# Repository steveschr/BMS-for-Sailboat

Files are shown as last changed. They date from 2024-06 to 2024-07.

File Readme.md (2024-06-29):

# Fully configurable BMS and charge controller with balance for 4S LiFePO4 battery bank on a cruising sailboat.  

# Description & Purpose

* Prevents load dump by controlling charge sources.
* Measures and monitors pack and cell voltage as well as current load/charge of battery.  
* Starts and stops charge sources at user defined limits.  The charge sources are then programmed as desired.
* All settings as well as errors saved to EEPROM.  
* Single knob control with 4 line LCD display.  
* Configurable alarm thresholds.
* External alarm ready 
* Pack disconnect function ready as suggested by ABYC.  
* Can easily be modified for seperate charge & load busses.
* Charge lockout below freezing.

# Genesis

I wanted to install LiFePO4 batteries on my cruising sailboat and didn't like the feature set of the available BMS and control system options.  I didn't like the idea of a drop in battery that might decide to disconnect or do a load dump when it wanted to.  (On a boat that means the worst possible moment)  I didn't want to add a start battery and the associated inefficiencies and complexity.  When I started this project there wasn't much hardware available.  That's changed some but I still like this better.
For example I may want to keep the batteries at a specific SOC instead of charging to full all the time.  There's no way the alternator regulator or solar controller can know state of charge except by voltage.  I wanted control by SOC and voltage as well as full BMS protection.
Determinining lithium battery state of charge (SOC) by cell voltage alone is too imprecise and it's impossible to determine health of pack by pack voltage.
  
After trying a few other methods I ended up using a simple resistor voltage divider circuit for the front end.  Yeah I guess I feel a little embarassed I didn't do something more sophisticated but since there's only 4 cells in series it works well, the biggest trouble is error trapping for an open cell connection.

I've been using this system successfully for several years.   

# Credits
Stuart Pittaway - Lot's of inspiration here.  Robert Kirberich (solder-stencil.me), Majenko Technologies (MCP3208 library), lots of snips from around the net I can't recall to credit, MCUDude for Mightycore

# Operation 
Cell voltage is determined by resistor voltage dividers and MCP3208 analog to digital converter.  
Accuracy better than +-5 mV.  Can be tuned for variations in resistor values.  Current is read by a 200A 50mV shunt output amplified by INA213 and read by MCP3204.  
27mA current draw, 68mA when LCD lit.  The drain caused by the resistor dividers is .25mA or less per cell.

# Construction
Main board, Balance board, temperature sensor boards and current shunt board.  A combination of surface mount and through hole components.  I assembled these with the printed stencil and a hot plate for the surface mount.
EasyEDA format schematic & board as well as gerbers for all.  STL files for 3d printing of required cases and mounting bases.
3D print using PetG or similar.  PLA is too brittle.  Boards & LCD fit on printed pins, flatten pins with a soldering iron.  No screws needed.
3D printed stencil for main board (Thank you to https://solder-stencil.me/ )
Compiled on Arduino IDE with MCUdude's excellent MightyCore (Atmega644/BOD 4.3/No Bootloader/External 16MHz/LTO Enabled/Bobuino/644-644A  Required LCD & MCP3208 libraries included.  Any compatible programmer should work, I use STK500, Atmel ICE, Tiny USB.

Main board

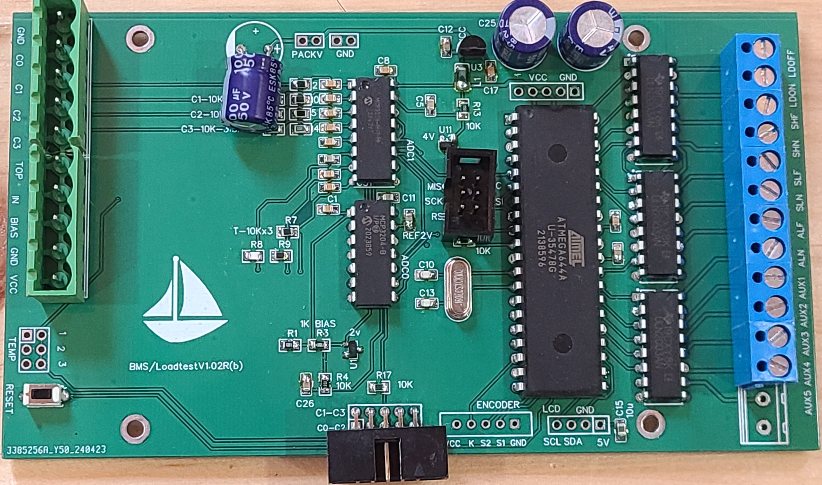
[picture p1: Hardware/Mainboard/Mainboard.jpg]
main board


Shunt board

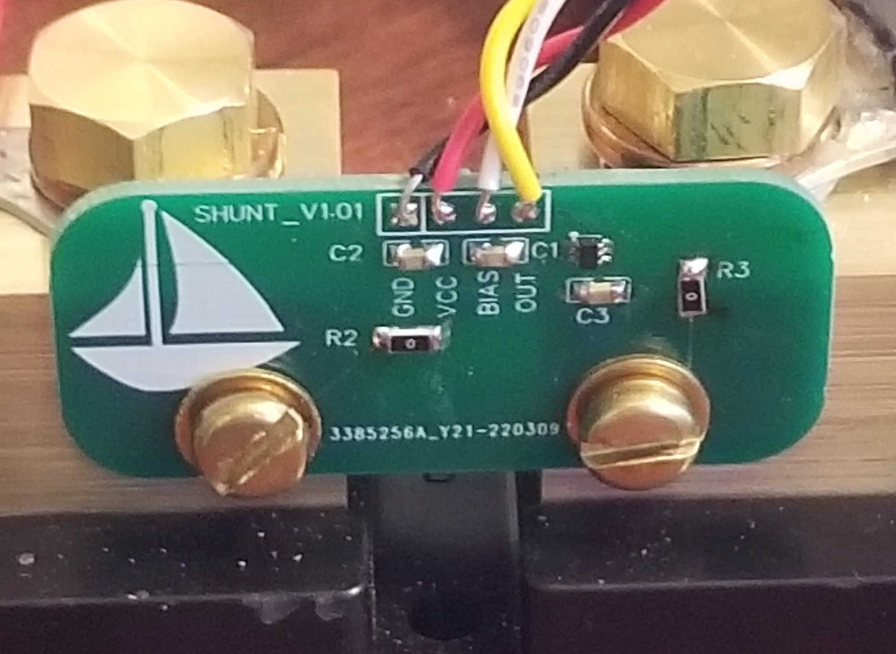
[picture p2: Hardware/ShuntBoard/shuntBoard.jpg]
shunt board


Balance board

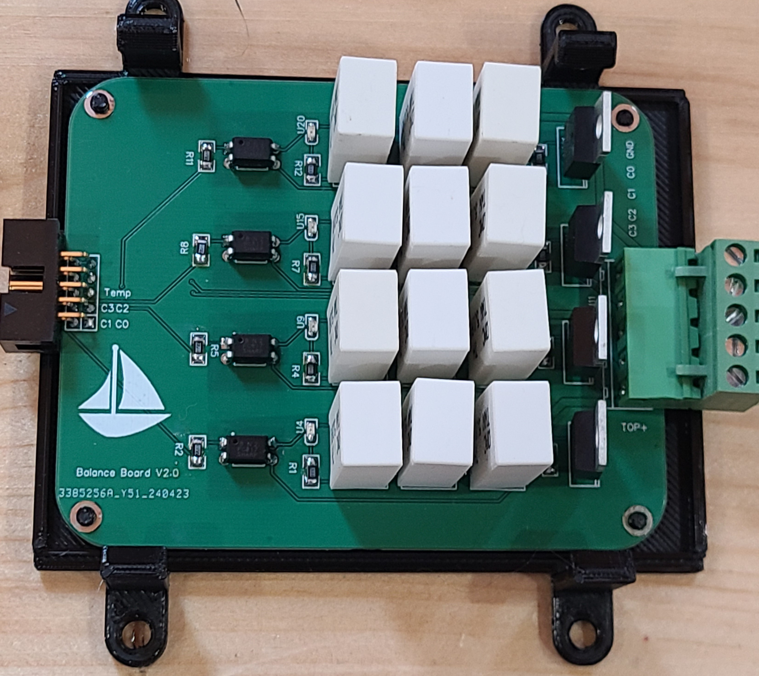
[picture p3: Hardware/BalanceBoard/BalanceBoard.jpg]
balance board


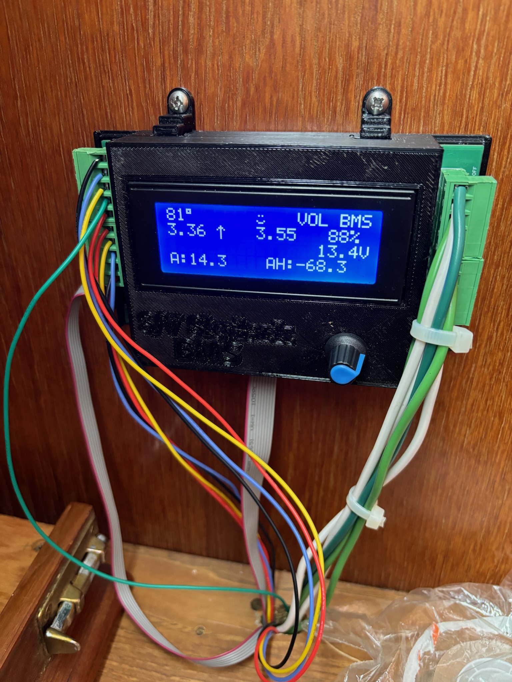
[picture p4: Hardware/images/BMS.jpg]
  

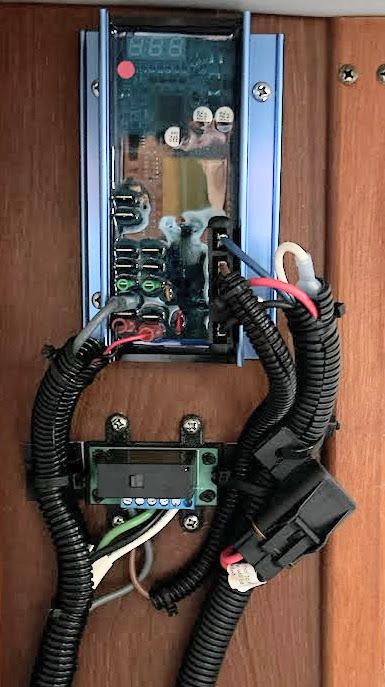
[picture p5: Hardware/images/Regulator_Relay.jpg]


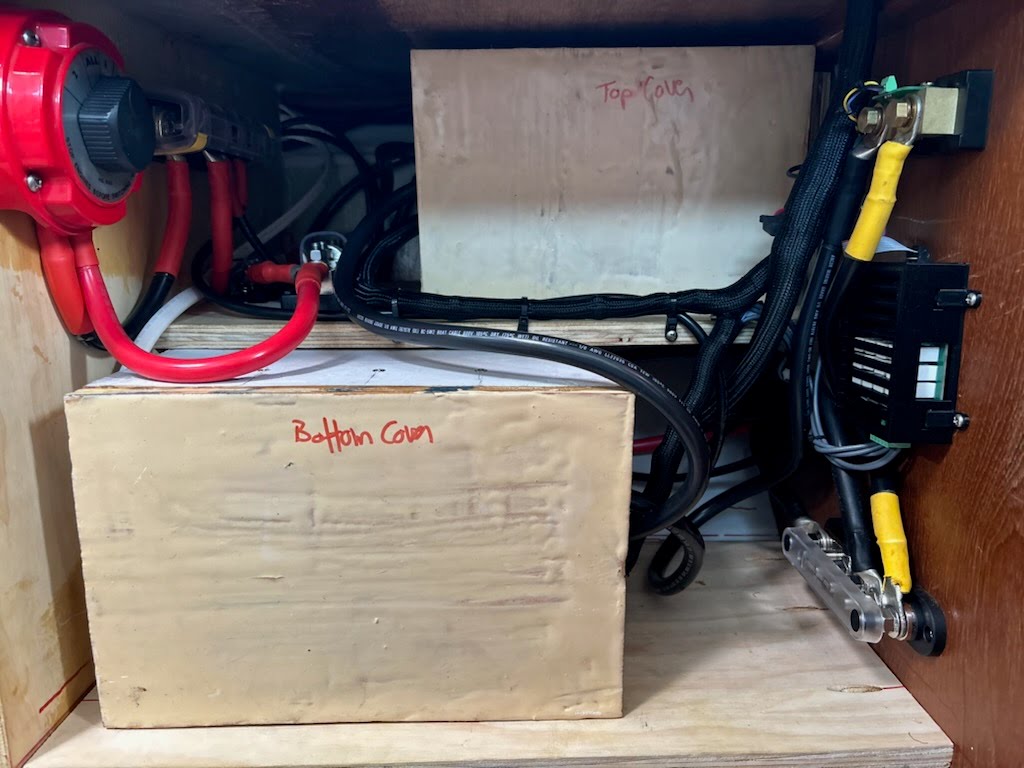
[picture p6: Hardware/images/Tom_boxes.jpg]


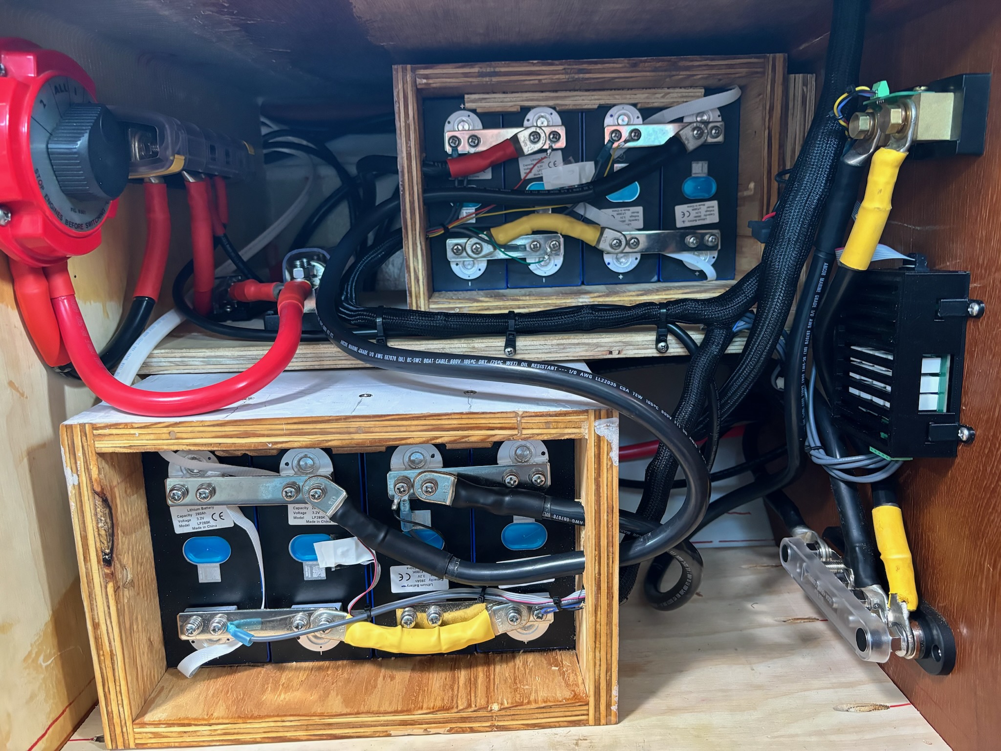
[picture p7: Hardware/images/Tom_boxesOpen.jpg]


# hardware
Atmega 644 based.  

# Software
Compiled on Arduino IDE with MCUdude's excellent MightyCore

# BOM

There's a set of BOMs in the hardware folder, 1 for each board.  Wiring and terminal blocks are in the [Extras BOM](Hardware/extrasbom.md)

# Installation
## Modifications to boat
Install latching relays to control AC input to shore charger, solar panel input to solar charger, ign signal to alternator relay.  Provision for latching relay to protect bank; I have a friend that uses this to shut off the fridge when the dock power goes out for long enough to drain the battery.  See [the overview](./Schematic_Typical-Layouts.pdf) and an [as built](./LittleWillieAsBuilt.pdf)
My boat is out of the water in the summer, I disconnect the BMS from the battery and the battery from the boat for storage.

# Warning
Lithium batteries can be dangerous.  If you build and or use this device it's at your own risk.

# Details
See individual hardware folders.

# Future Plans
Maybe add Bluetooth.  Add terminal connectors for the battery temp sensors.

## Parameter Menu Settings

Bank Capacity 
Total bank capacity in AmpHours.

Start Charge
When in Volt charge mode triggers start charge.  Constrained to a minimum of 60mV below StopCharge Voltage

Stop Charge
In either Volt or SOC charge mode triggers stop charge.  Constrained to a minimum of 50mV above StartCharge Voltage

SOC Start  
% charge to start charging when in SOC mode.

SOC Stop 
% charge to stop charging when in SOC mode.  Voltage also affects charge stop in SOC mode.

Charge Mode 
SOC or Voltage. In SOC mode, Charge will start if measured SOC falls below SOCstart parameter (Ignores Start Charge V )  and will stop when either SOC Stop or Stop Charge V is reached.  If Stop Charge V is set relatively low, charge will start again as voltage falls below the stop threshold and continue cycling until calculated SOC reaches a level above SOC Start.   SOC will NOT reach SOC stop in this scenario.

Charging starts when, depending on mode either SOC or voltage falls below start threshold.
Charging stops when depending on mode either voltage or SOC target is met or either temperature hi or low or voltage high (this is redundant) alarm is set.

When in VOL mode the 2nd row of the display shows current cell voltage on left and target voltage on right.  Up arrow for charging or ready charge and down arrow for not charging.  Target voltage is either start or stop voltage depending on whether charging or discharging.

When in SOC mode target SOC is on the left, current SOC on right.  Arrow indicates charge or discharge.  In both modes the up arrow indicates charge or charge ready and is not an indicator of actual charging status which is visible in the bottom left of the display.   

Chg To Full Now 
Starts charging as if the start parameter had been reached.  Charge continues until the stop parameter in current chargeMode is reached.

Efficiency 
% efficiency of charge.  No Peukert’s calculation as it’s assumed to be about 1 for LiFePo4.

HV Alarm
High Voltage Alarm. Sets alarm & stops charge.  Clears at -5mV.

LV Alarm 
Low Voltage Alarm. Sets alarm & allows charge.  Clears at +5mV

HV Disconnect
Assuming a bank protection relay boat & charging shut off until voltage falls below HVAlarm.  Will not stop the boat if PackVoltage < 15.6v.

LV Disconnect
Assuming a bank protection relay; boat & charging shut off until voltage rises above LVAlarm. 
Will not stop the boat if PackVoltage > 10.0v.

maxDrift
In millivolts.  If setting is reached an alarm will set but charging will continue.

C0Trim  C1Trim  C2Trim  C3Trim 
Enter in mV any offset required so the display matches actual cell voltages.  

Balance Allow V 
Voltage to start balance.  Highest cell is used.  Needs the balance board connected.  

Show Cells 
1st screen shows voltage of all cells, # of charge cycles since startup, cell drift in mV and # of times each cell has been balanced.  2nd screen shows system voltages, 3rd screen shows hi & lo cell, amperage, drift, pack & total voltage at end of last charge cycle.

Show Temps
Shows temp sensor readings battery & balance board

Show Alarms
Shows all saved previous alarms, key sensor readings at last alarm and alarm flags that were set at the time of last alarm.

Clear Alarm
Clears all active & inactive alarms.

Mode 
Choose BMS, OFF or DUM.  DUM turns on the boat and allows charging with no protection.  DUM mode display shows highest cell voltage and SOC.   Switching back to BMS restores full management.  OFF mode prevents charging. 

Encoder Direction
Changes direction of the encoder knob.  Used only for initial setup if required.  The change is immediate so twisting the knob in one direction changes the value 1-0-1-0-1-0 etc.

SOC
Set current SOC   This may be useful for initial install or testing.

Shunt Polarity 
Allows connecting shunt in either direction.  Use if Amps display reversed.

Number of Temp Sense
Choose correct # of battery temp sensors used

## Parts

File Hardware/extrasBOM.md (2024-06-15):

# Additional parts

* You'll need some of this stuff too.

[Relay ADJH24112 - for control of charge sources](https://www.digikey.com/en/products/detail/panasonic-electric-works/ADJH24112/7537062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)

[Relay G9TB-K1ATH-E DC12  - 120A for load or charge bus](https://www.digikey.com/en/products/detail/omron-electronics-inc-emc-div/G9TB-K1ATH-E-DC12/8593134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)

[24ga silicone wire](https://www.aliexpress.us/item/3256806064207395.html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) 

[Quick disconnects for wire to board](https://www.aliexpress.us/item/2251832631116552.html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) But the pins are oversize and must be trimmed.

[Or terminal blocks ED120/5DS](https://www.digikey.com/en/products/detail/on-shore-technology-inc/ED120-5DS/265403)

[Terminal block for shunt board OSTVN04A150](https://www.digikey.com/en/products/detail/on-shore-technology-inc/OSTVN04A150/1588864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)

[Rotary encoder](https://www.aliexpress.us/item/3256802224106936.html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)

[STK 500 programmer](https://www.aliexpress.us/item/3256806049996635.html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)

[I2c 20x4 LCD](https://www.aliexpress.us/item/3256801435340143.html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)

[Balance interface cable 1.27 pitch 10 conductor](https://www.aliexpress.us/item/2251832811689611.html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)

[Cable ends 2x5](https://www.aliexpress.us/item/3256802188284715.html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)

[Header connector wire to board 2.54 2x5](https://www.aliexpress.us/item/3256805956473629.html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)

[Murata 3020-01101-0 shunt or similar](https://www.mouser.com/ProductDetail/Murata-Power-Solutions/3020-01101-0?qs=35WhQNrE6p34sz4RDoVvJQ%3D%3D)

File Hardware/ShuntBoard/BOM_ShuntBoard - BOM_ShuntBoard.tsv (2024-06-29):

Name | Designator | Footprint | Quantity | Manufacturer Part | Manufacturer
0R | R2,R3 | 1206 | 2
.1uF | C2,C3 | C0805 | 2 | KGM21NR71E104KT | DELETE C1
INA214AIDCKR | U1 | SC-70-6_L2.2-W1.3-P0.65-LS2.2-BR | 1 | INA214AIDCKR | TI

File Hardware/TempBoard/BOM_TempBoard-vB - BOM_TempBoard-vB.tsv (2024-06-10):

Name | Designator | Footprint | Quantity | Manufacturer Part | Manufacturer
NTCS0805E3103FLT | R2 | R0805 | 1 | NTCS0805E3103FLT

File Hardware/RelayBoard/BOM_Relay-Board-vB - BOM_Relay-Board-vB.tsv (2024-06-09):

Name | Designator | Footprint | Quantity | Manufacturer Part | Manufacturer
ADJH23012 | U1 | RELAY-TH_PANASONIC_ADJH241XX | 1 | ADJH24112 | PANASONIC

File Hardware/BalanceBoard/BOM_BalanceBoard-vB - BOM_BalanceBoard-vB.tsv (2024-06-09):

Name | Designator | Footprint | Quantity | Manufacturer Part | Manufacturer
IRLB8743PBF | Q1,Q2,Q3,Q4 | TO-220(TO-220-3) | 4 | IRLB8743PBF | IR
100 | R1,R4,R7,R12 | R1206_1 | 4 | RT1206FRE07100RL
220 | R2,R5,R8,R11 | R1206_1 | 4 | RT1206FRE07220RL
100K | R3,R6,R10,R13 | R1206_1 | 4 | RT1206FRE07100KL
NTCS0805E3103JHT | R9 | R0805 | 1 | NTCS0805E3103JHT | Vishay Intertech
TWW5J1R0E | U1,U2,U3,U6,U7,U8,U12,U13,U14,U17,U18,U19 | RES-TH_L12.5-W9.0-P5.00-D1.2 | 12 | TWW5J1R0E | Ohmite
SM0805YCL | U4,U9,U15,U20 | LED0805-RD | 4 | SM0805YCL
FOD817A300 | U5,U10,U16,U21 | DIP-4 | 4 | FOD817A300

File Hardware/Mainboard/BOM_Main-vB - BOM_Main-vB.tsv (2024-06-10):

Name | Designator | Footprint | Quantity | Manufacturer Part | Manufacturer
MCP3204-CIP | ADC0 | DIP14 | 1 | MCP3204-BI/P | Microchip Tech
MCP3208-CI_P | ADC1 | DIP16 | 1 | MCP3208-BI/P | Microchip Tech
ATMEGA644A-PU | AT1 | PDIP-40 | 1 | ATMEGA644A-PU | Microchip Tech
.1u | C1,C4,C5,C6,C7,C8,C9,C11,C12,C17,C18,C31,C15,C22 | C0805 | 14 | KGM21NR71E104KT
100uF | C2,C3,C25 | CAP-TH_BD10.0-P5.00-D1.0-FD | 3 | ESK107M050AH1AA
22pF | C10,C13 | C0805 | 2 | C0805C220K3GAC7800
10u | C26 | C0805 | 1 | C0805C106K3PAC7800
1-87215-2 | ICSP | HDR-TH_6P-P2.54-V-M-R2-C3-S2.54-1 | 1 | 1-87215-2 | TE Connectivity
1uH | L1 | L1206 | 1 | ILSB1206ER1R0K
1K | R1,R3,R11, R13, R4 | 805 | 5 | RT0805BRD071KL
10K | R2,R6,R7,R8,R9,R10,R12,R15,R17 | 805 | 9 | RT0805BRD0710KL
5K | R5 | 805 | 1 | RT0805BRD075K1L
3.33K | R14 | 805 | 1 | RT0805BRD073K3L
EVQ-PE505K | RESET | EVQPE505K | 1 | EVQPE505K
LM4040DELT-2.0 | U1 | SOT-23-3_L2.9-W1.3-P1.90-LS2.4-BR | 1 | LM4040CELT-2.0
ULN2003AN | U2,U4,U5 | DIP-16_16P-L20.2-W6.6-P2.54-LS7.6-BL | 3 | ULN2003AN | TI
LP2950ACZ-5.0G | U3 | TO-92-3_L4.9-W3.7-P1.27-L | 1 | LP2950ACZ-5.0/NOPB | ON
LM4040DELT-4.096 | U11 | SOT-23-3_L2.9-W1.3-P1.90-LS2.4-BR | 1 | LM4040CELT-4.1
16Mhz | Y1 | HC49US | 1 | ECS-160-18-4X-CKM

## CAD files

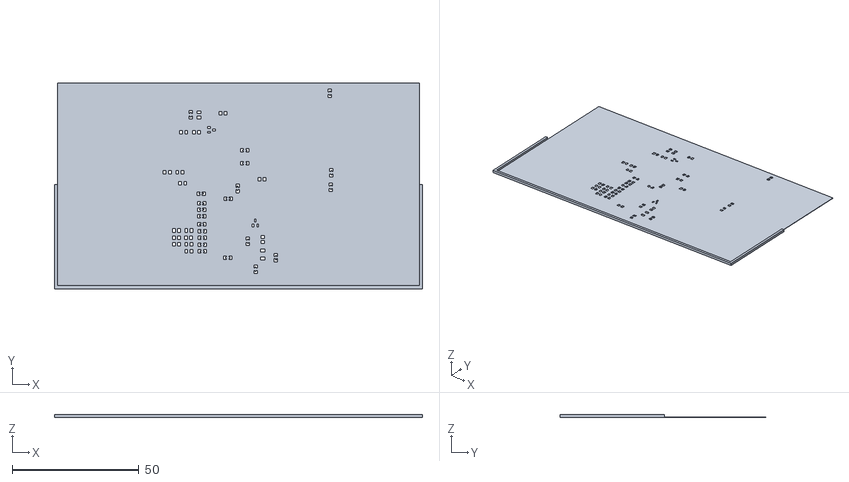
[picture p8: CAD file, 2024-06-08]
Hardware/Mainboard/BMS_Main_Stencil.stl
145.4 x 81.2 x 1.20

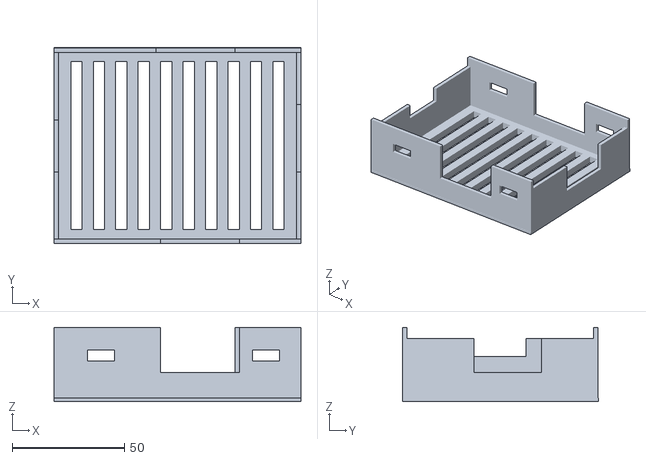
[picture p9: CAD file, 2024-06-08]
Hardware/BalanceBoard/BalanceBoardLid.stl
110.0 x 87.5 x 33.0

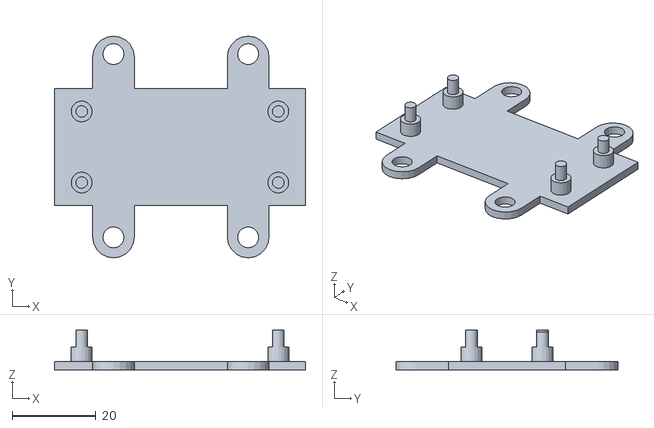
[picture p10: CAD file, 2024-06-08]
Hardware/RelayBoard/RelayBase.stl
60.0 x 53.0 x 9.50

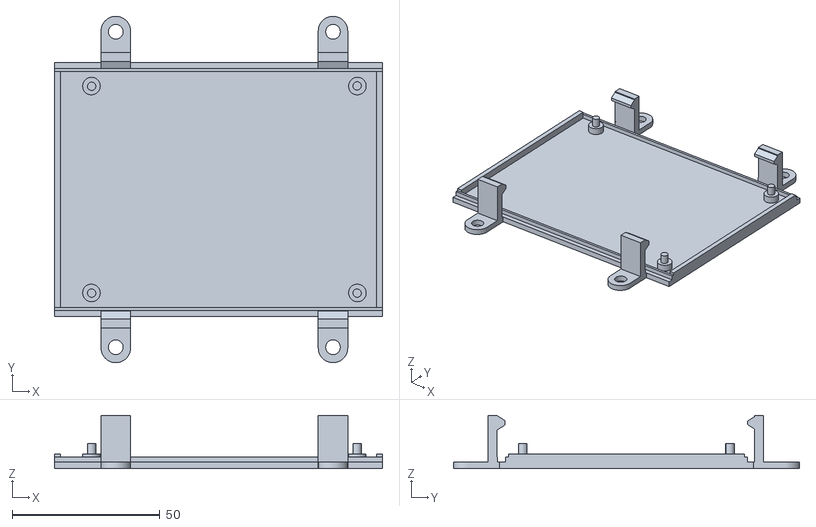
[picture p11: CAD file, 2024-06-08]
Hardware/BalanceBoard/BalanceBoardBase.stl
111.0 x 117.2 x 18.0

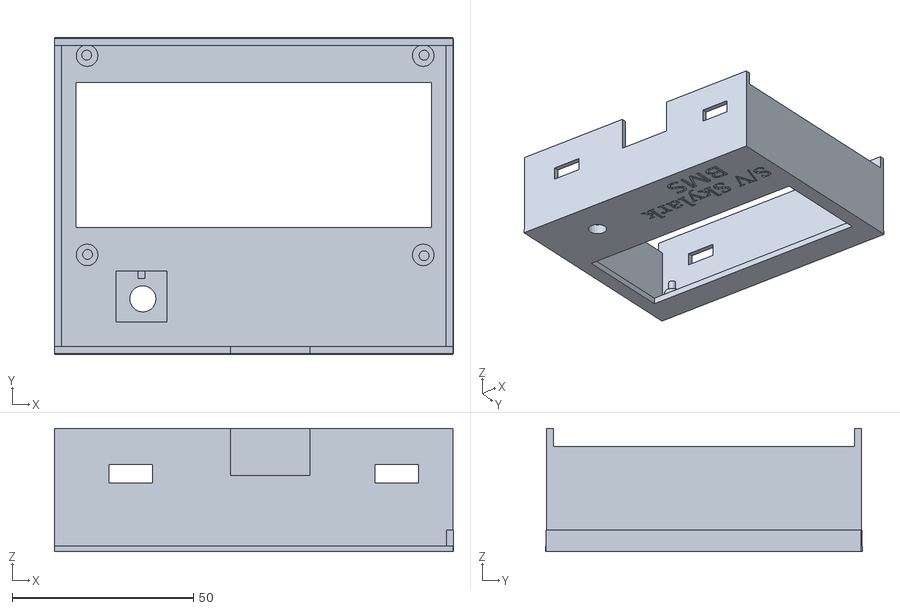
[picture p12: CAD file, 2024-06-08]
Hardware/Mainboard/BMS644Lid-w-pins.stl
110.1 x 87.5 x 34.0

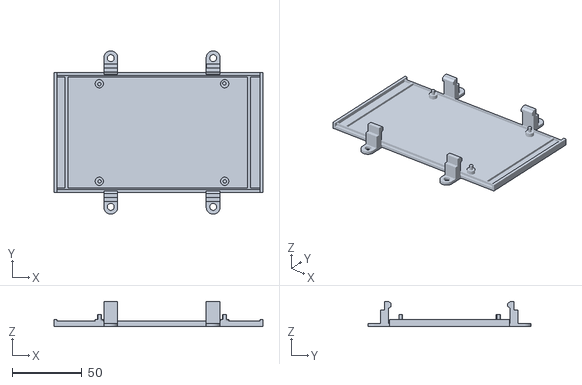
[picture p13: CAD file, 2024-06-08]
Hardware/Mainboard/BMS644Base.stl
150.0 x 117.2 x 18.0

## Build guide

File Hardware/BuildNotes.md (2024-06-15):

* Schematics & boards are in EasyEDA format, gerbers are also in the folders
* There are some errors in the part #s on the schematics but the BOMs are correct.

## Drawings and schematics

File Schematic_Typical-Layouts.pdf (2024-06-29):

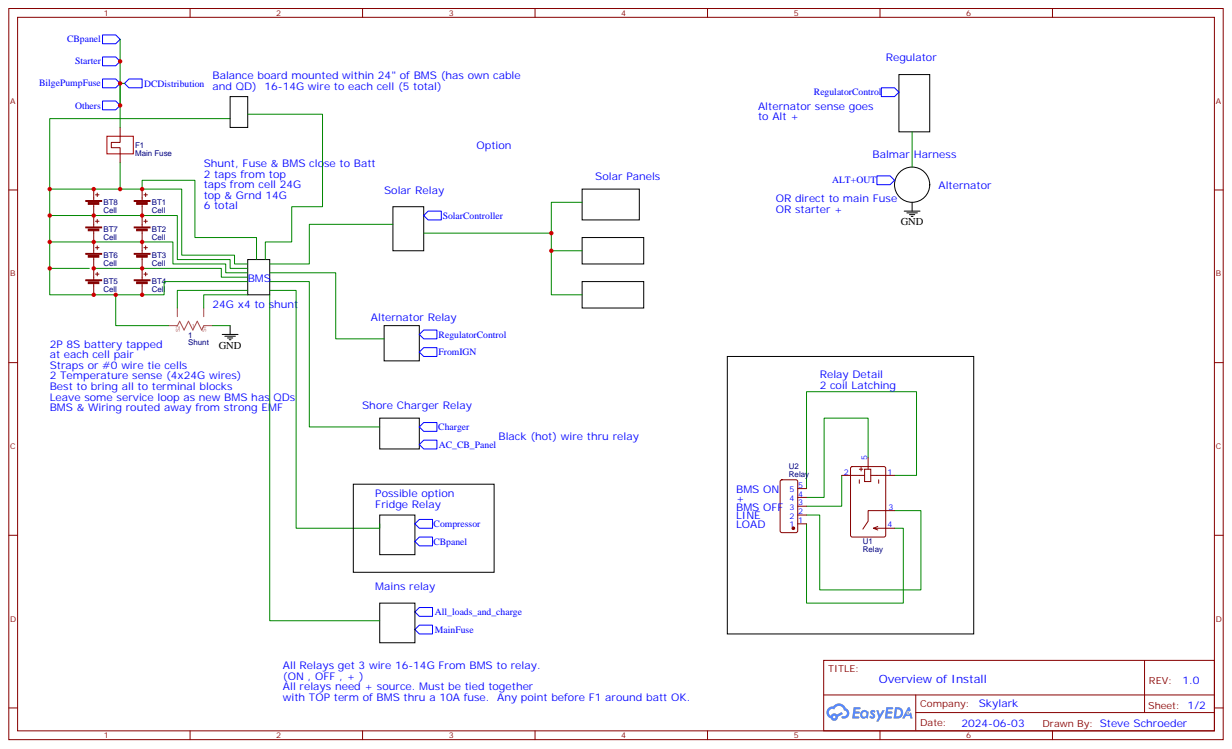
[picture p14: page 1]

Balance board mounted within 24" of BMS (has own cable
and QD) 16-14G wire to each cell (5 total)

Shunt, Fuse & BMS close to Batt
2 taps from top
taps from cell 24G
top & Grnd 14G
6 total

OR direct to main Fuse
OR starter +

2P 8S battery tapped
at each cell pair
Straps or #0 wire tie cells
2 Temperature sense (4x24G wires)
Best to bring all to terminal blocks
Leave some service loop as new BMS has QDs
BMS & Wiring routed away from strong EMF

Black (hot) wire thru relay

All Relays get 3 wire 16-14G From BMS to relay.
(ON , OFF , + )
All relays need + source. Must be tied together
with TOP term of BMS thru a 10A fuse. Any point before F1 around batt OK.

Drawn By: Steve Schroeder

OR

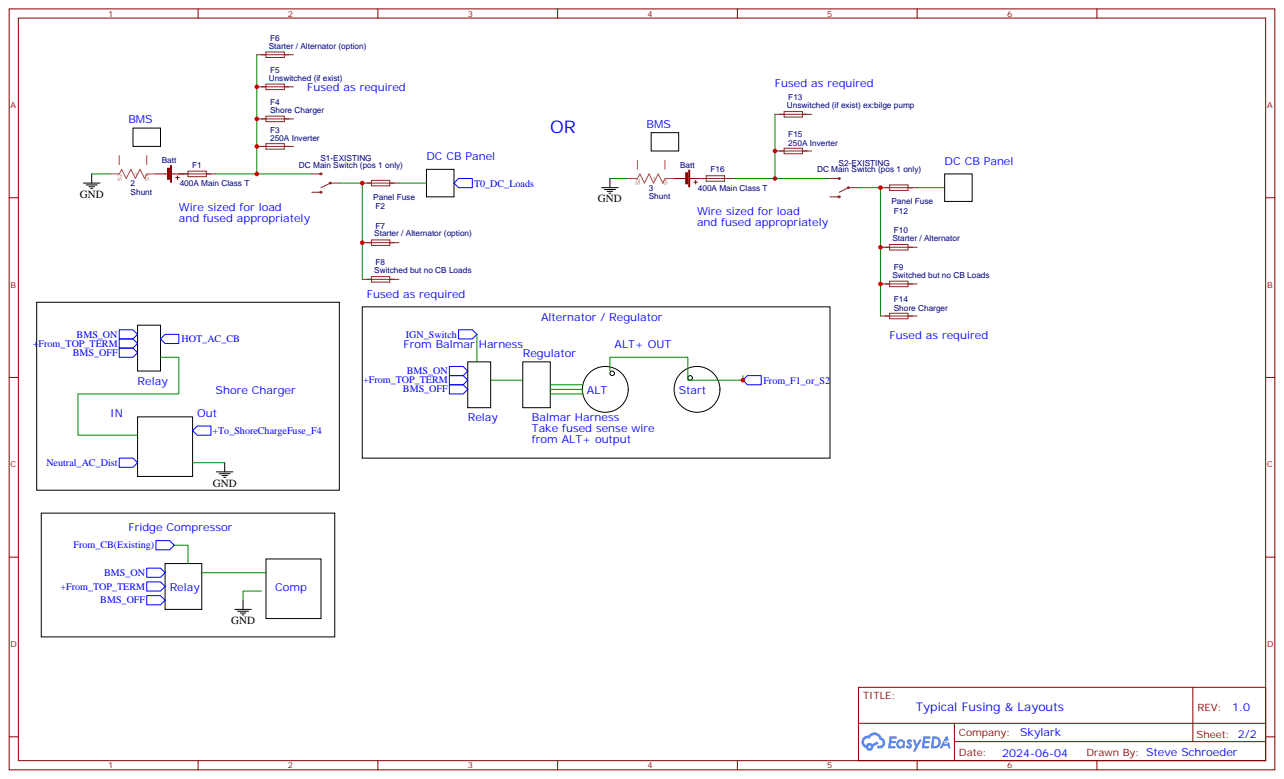
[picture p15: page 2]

Fused as required
Unswitched (if exist) ex:bilge pump

S1-EXISTING
DC Main Switch (pos 1 only)

Batt
400A Main Class T
Wire sized for load
and fused appropriately

S2-EXISTING

Switched but no CB Loads

Balmar Harness
Take fused sense wire
from ALT+ output

Drawn By: Steve Schroeder

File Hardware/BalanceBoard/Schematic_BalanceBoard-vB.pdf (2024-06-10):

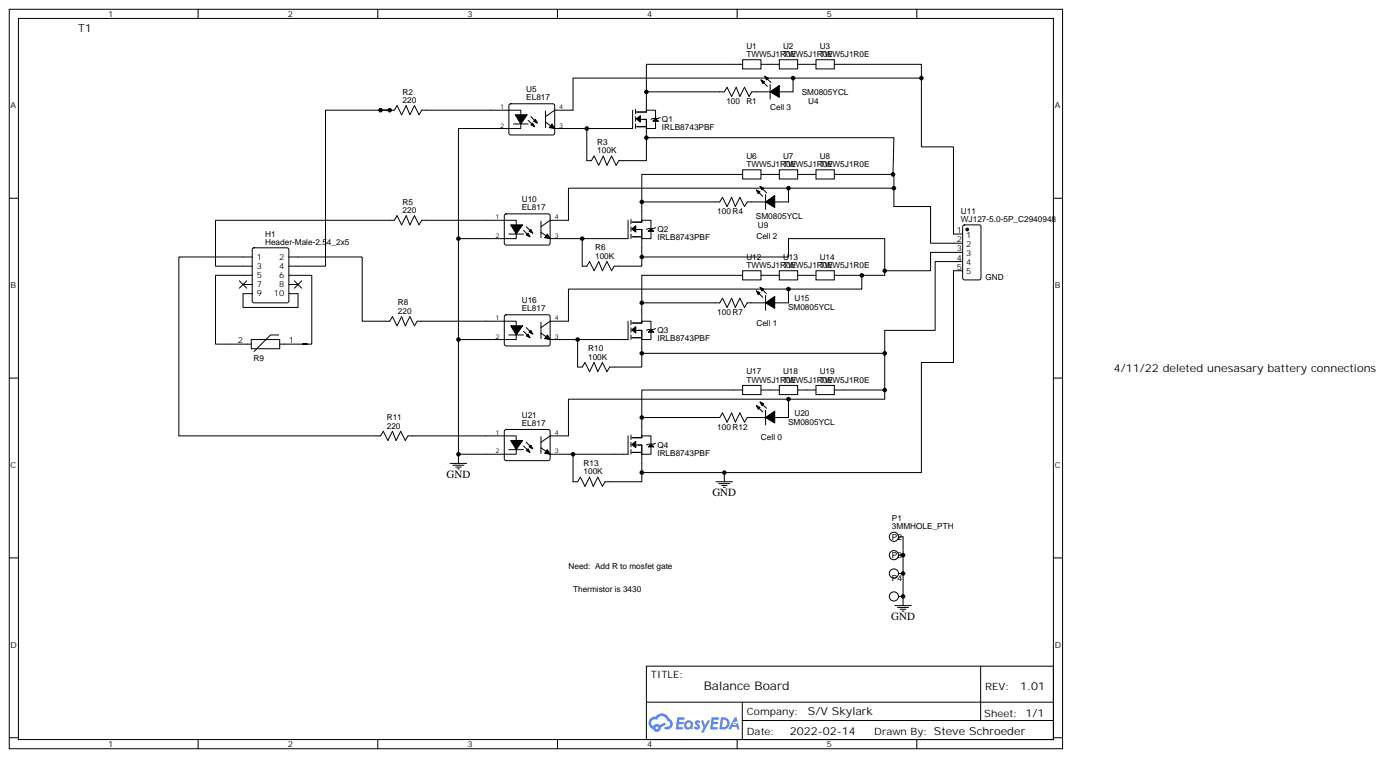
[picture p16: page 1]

4/11/22 deleted unesasary battery connections

Need: Add R to mosfet gate

Drawn By: Steve Schroeder

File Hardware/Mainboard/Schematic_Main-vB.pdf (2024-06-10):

## Ordered boards 4/22/24 BMS/LoadtestV1.02R(b)

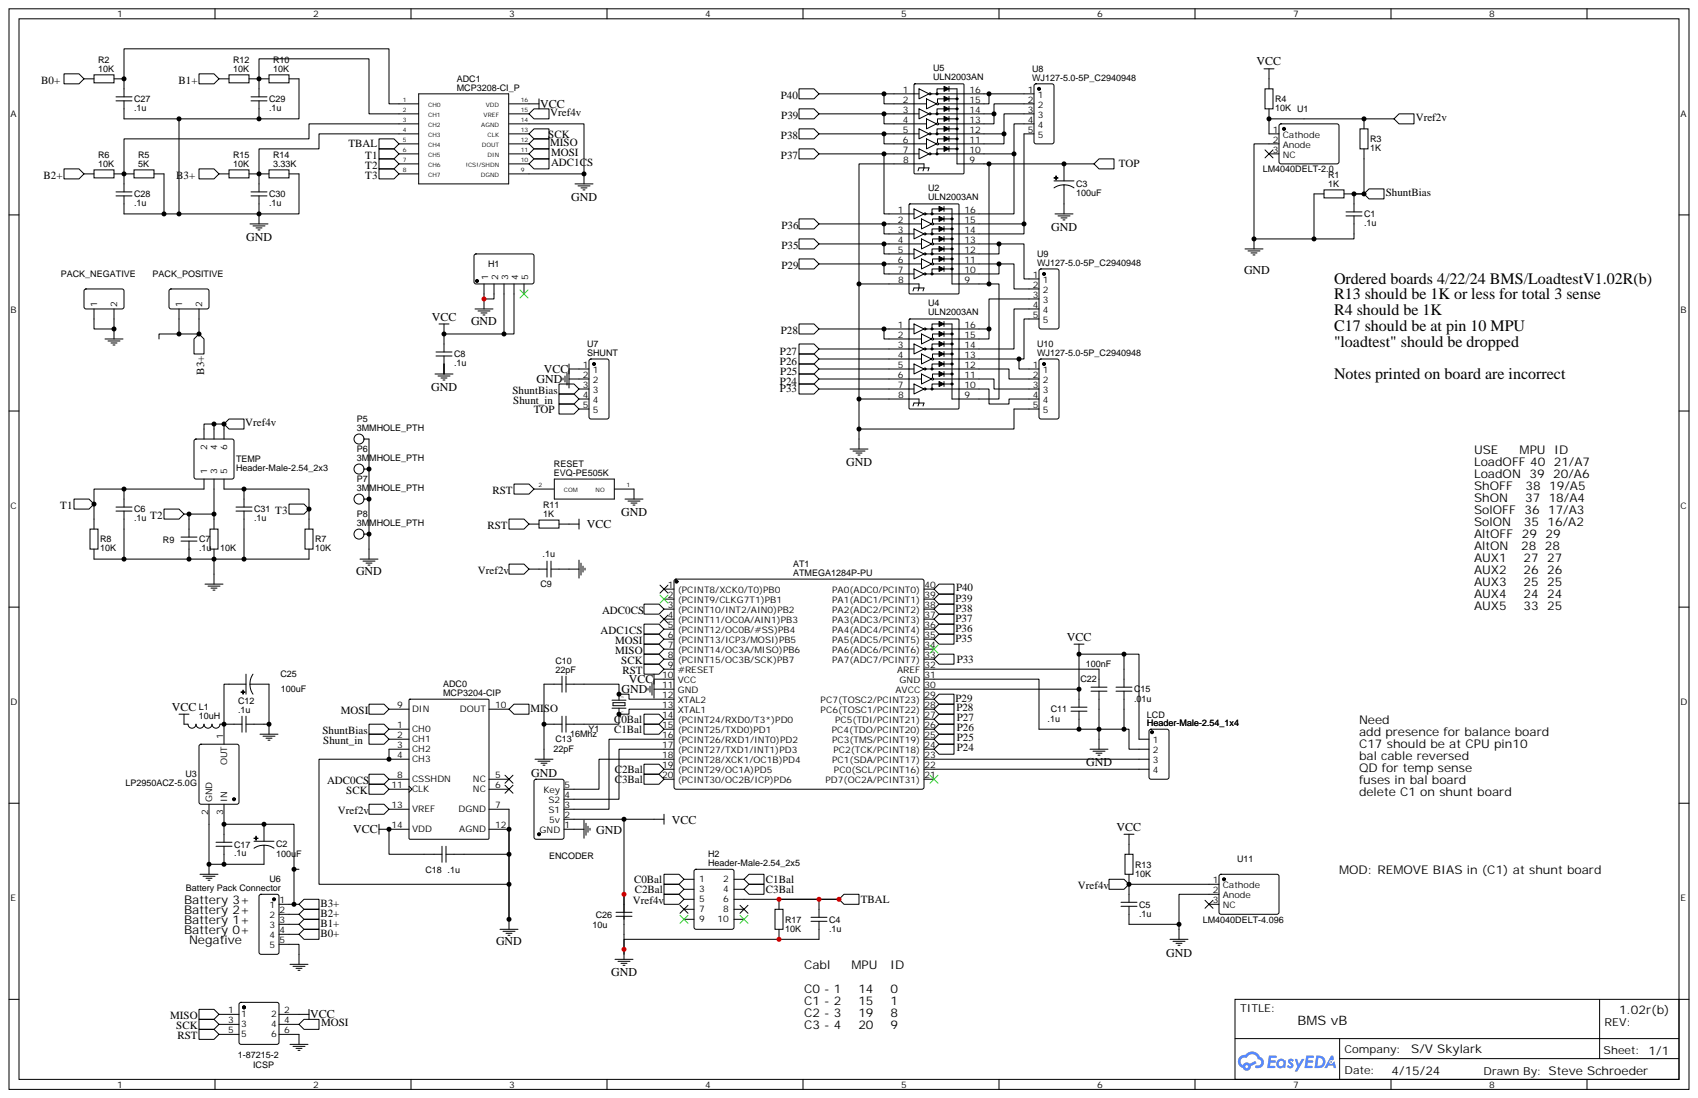
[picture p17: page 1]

R13 should be 1K or less for total 3 sense
R4 should be 1K
C17 should be at pin 10 MPU
"loadtest" should be dropped
Notes printed on board are incorrect

Need
add presence for balance board
C17 should be at CPU pin10
bal cable reversed
QD for temp sense
fuses in bal board
delete C1 on shunt board

MOD: REMOVE BIAS in (C1) at shunt board

Drawn By: Steve Schroeder

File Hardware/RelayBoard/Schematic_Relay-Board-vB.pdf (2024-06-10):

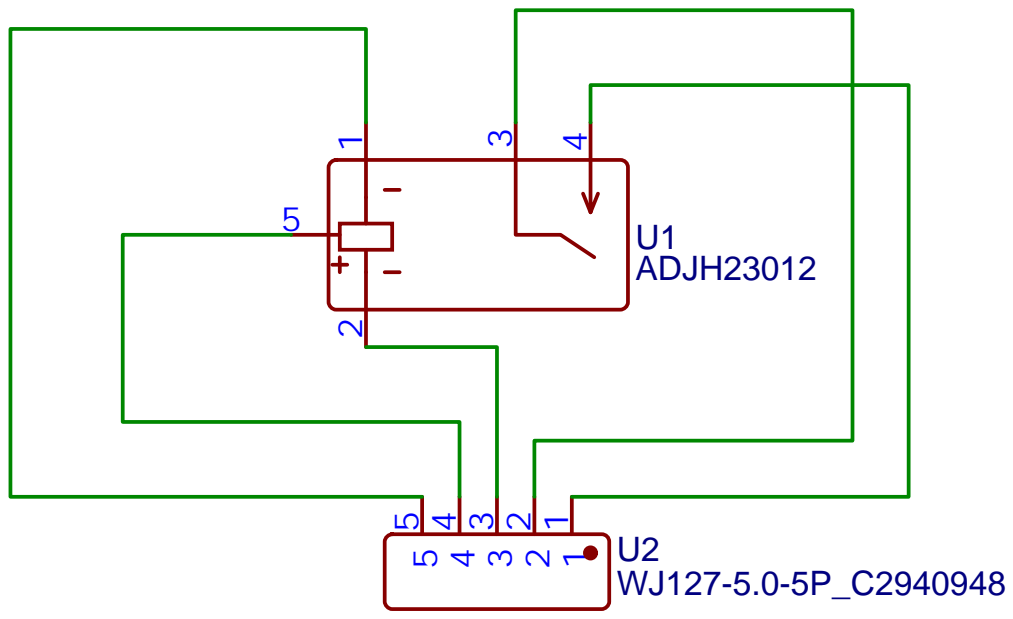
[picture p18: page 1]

Drawn By: Steve Schroeder

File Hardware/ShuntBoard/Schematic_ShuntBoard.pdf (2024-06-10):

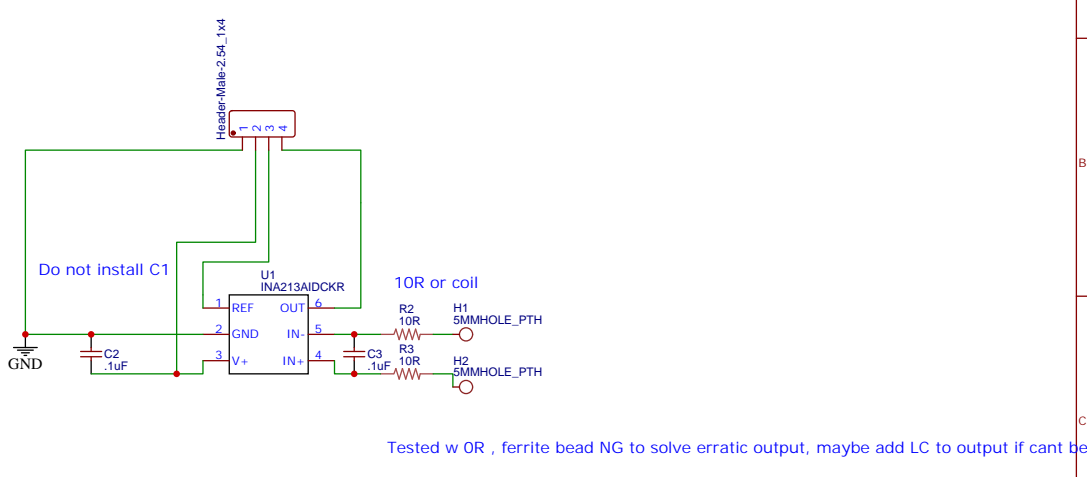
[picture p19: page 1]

Tested w 0R , ferrite bead NG to solve erratic output, maybe add LC to output if cant be fixed in code

Drawn By: Steve Schroeder

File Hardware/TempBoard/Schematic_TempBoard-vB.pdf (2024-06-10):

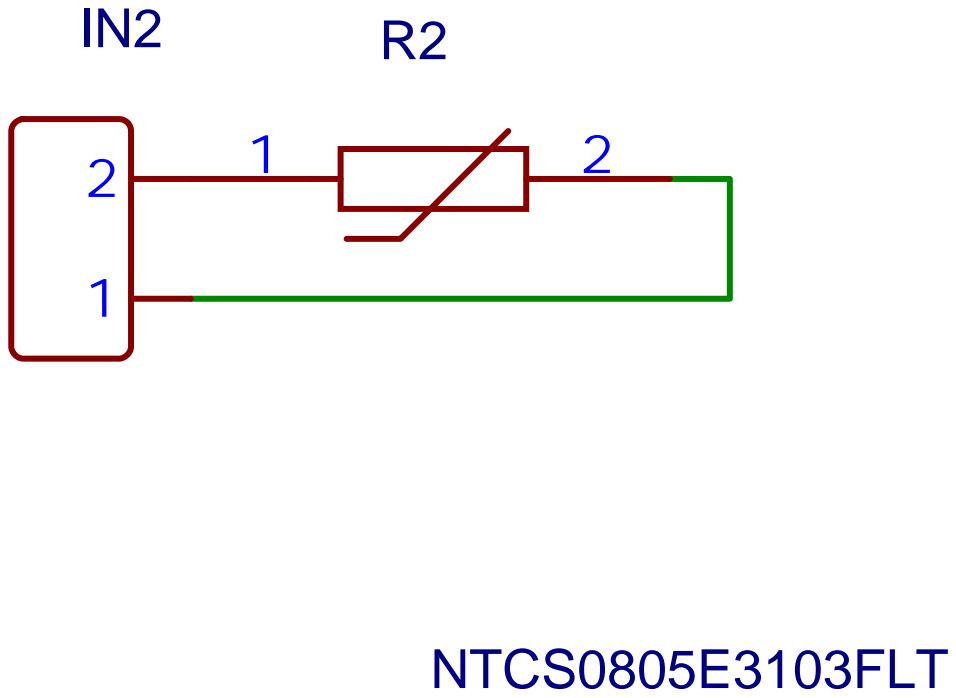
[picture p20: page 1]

Drawn By: Steve Schroeder

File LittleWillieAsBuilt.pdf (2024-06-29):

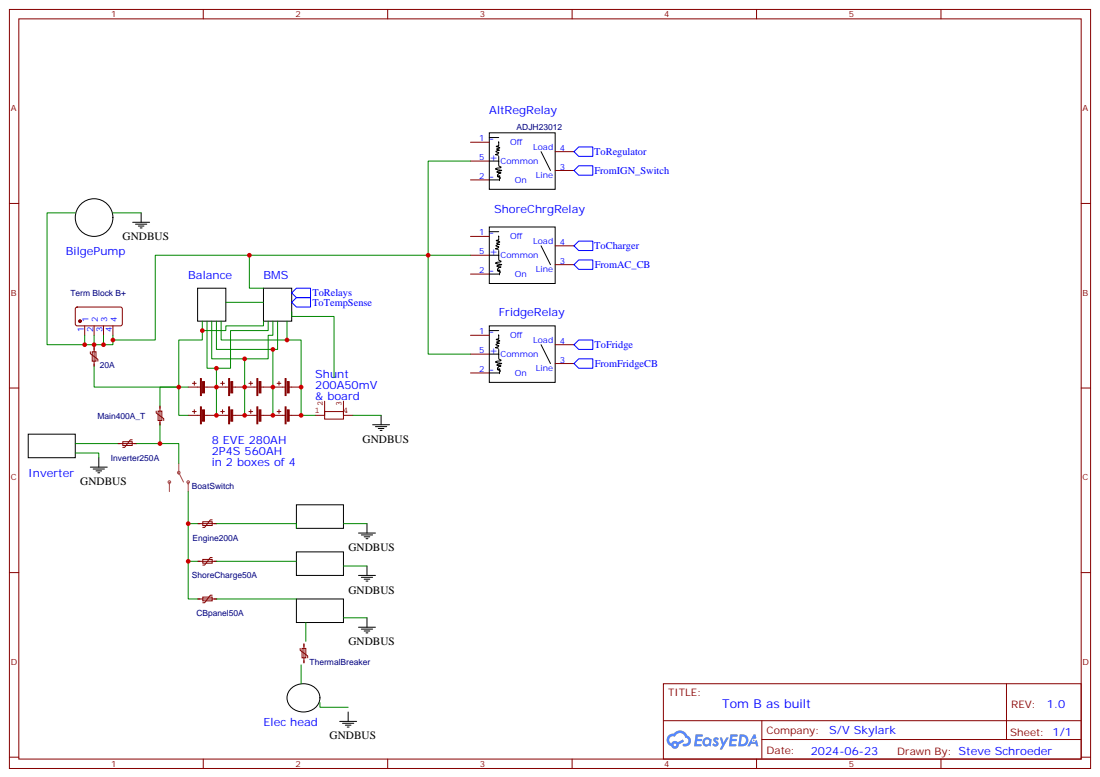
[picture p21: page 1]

Drawn By: Steve Schroeder

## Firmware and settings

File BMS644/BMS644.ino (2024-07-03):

#include "LiquidCrystal_I2C.h"
LiquidCrystal_I2C lcd(0x27, 20, 4);
#include "parameters.h"
#include <SPI.h>
#include <EEPROM.h>
#include "customChar.h"
#include "MCP3208.h"

MCP3208 adc0(adcU0);
MCP3208 adc1(adcU1);

void setup() {
  pinMode(encpin1, INPUT);  // Pin 2
  pinMode(encpin2, INPUT);  // Pin 3
  pinMode(adcU0, OUTPUT);
  pinMode(adcU1, OUTPUT);
  pinMode(encButton, INPUT);
  pinMode(ALARMpin, OUTPUT);  // AUX4 pin
  pinMode(AcChrge_OFF, OUTPUT);
  pinMode(AcChrge_ON, OUTPUT);
  pinMode(Solar_OFF, OUTPUT);
  pinMode(Solar_ON, OUTPUT);
  pinMode(Alt_OFF, OUTPUT);
  pinMode(Alt_ON, OUTPUT);
  pinMode(Load_ON, OUTPUT);
  pinMode(Load_OFF, OUTPUT);
  pinMode(AUXpin1, OUTPUT);
  pinMode(AUXpin2, OUTPUT);
  pinMode(AUXpin3, OUTPUT);
  pinMode(AUXpin5, OUTPUT);  
  analogReference(DEFAULT);
  lcd.init();
  lcd.backlight();
  lcd.clear();
  for (byte j = 0; j <= 3; j++) {  //Balance outputs to MOSFETs
    pinMode(balancePins[j], OUTPUT);
  }
  flashBalanceLEDs();
  digitalWrite(adcU0, HIGH);
  digitalWrite(adcU1, HIGH);
  SPI.beginTransaction(SPISettings(1000, MSBFIRST, SPI_MODE0));  //
  delay(50);
  adc0.begin();
  delay(50);
  adc1.begin();
  delay(50);
  attachInterrupt(0, decoder, FALLING);
  lcd.createChar(smileFace, smiley);
  lcd.createChar(lockedFace, locked);
  lcd.createChar(anchorFace, anchor);
  lcd.createChar(bellFace, bell);
  lcd.createChar(downArrowFace, downArrow);
  lcd.createChar(emptyBoxFace, emptyBox);
  lcd.createChar(upArrowFace, upArrow);
  lcd.createChar(emptyBellFace, emptyBell);
  float T = getTemps(0);  
  startScreen();  //also copies config from EEPROM
  delay(100);
  lcd.clear();
  startBoat();
  ChargeON = 1;
  stopCharge();
  lockoutStartTime = millis();
  chargeLock = true;  
  for (int i = 0; i < numOfScreens; i++) {   //copy working array values to display array
  parameters[i][1] = parameters[i][0];
  }
  flashBalanceLEDs();
}


void loop() {
  getAdcAmps();
  getamphours();
  encoder();
  if (encButtonPressed) {
    lcd.backlight();
    bool gns = getNewScreen();
    if (gns) {
      encoder();
      inputAction();
    }
    lcd.clear();
    backlightTimer = millis();
  }

  if (millis() - backlightTimer > (timeInterval * 180UL)) {
    lcd.noBacklight();
  }

  if (millis() - DISPpreviousMillis > (timeInterval * 2UL)) {
    DISPpreviousMillis = millis();
    getAdc();
    if (currentMode == "BMS") {
      logic();
    }
    doBalance();    
    LCDstatus();
    if (millis() - lockoutStartTime > 30000UL) {
      chargeLock = false;
    }
    if (millis() - lockoutStartTimeSYS > 30000UL) {
      AlarmFlagSYS = false;
      flagCountSYS = 0;
      //    alarmOff();   ??   <<<<<<<<<<<<<<<<<<<<<<<<<<<<<<<<<<<<<<<<<<<<<<<<<<<<<<<<<<<<<<<<<<<<<<<<<<<<<<<<<<<<<<<<<,
    }
  }
}

float getTemps(int req) {  //3 on mainboard to ADC
  int hiindex = 0;
  int loindex = 3;
  float maxtemp = -500;
  float mintemp = 500;
  float K, C, F;
  if (parameters[SCRnumTsense][0] > 0) {
    for (int i = 5; i <= (5 + parameters[SCRnumTsense][0]); i++) {  //channel 5,6,7 ADC1 = temp array positions 0,1,2 for batts T sense
      int t = adc1.analogRead(i);
      K = 1.00 / (invT0 + invBeta * (log(4095 / (float)t - 1.00)));
      C = K - 273.15;                  // convert to Celsius
      F = ((9.0 * C) / 5.00) + 32.00;  // convert to Fahrenheit
      tempSensor[i - 5] = F;
    }
  } 

  int t = adc1.analogRead(balanceTempSensor);  //pin #4 of ADC
  K = 1.00 / (invT0 + invBeta * (log(4095 / (float)t - 1.00)));
  C = K - 273.15;                  // convert to Celsius
  F = ((9.0 * C) / 5.00) + 32.00;  // convert to Fahrenheit
  tempSensor[3] = F;


 if (parameters[SCRnumTsense][0] > 0){
  for (int i = 0; i < (parameters[SCRnumTsense][0]); i++) {  //get hi lo for batt T sensors
    if (tempSensor[i] > maxtemp) {
      maxtemp = tempSensor[i];
      hiindex = i;
    }
    if (tempSensor[i] < mintemp) {
      mintemp = tempSensor[i];
      loindex = i;
    }
  }
 }
 if (parameters[SCRnumTsense][0] == 1){
  maxtemp = tempSensor[0];
  hiindex = 0;
  mintemp = tempSensor[0];
  loindex = 0;  
 }


  if ((tempSensor[hiindex] >= 100.0) && (tempSensor[hiindex] - tempSensor[loindex] < 25)) {
    if (!AlarmFlagOT) {
      flagCountOT++;
      if (flagCountOT > 16) {
        AlarmFlagOT = true;
        alarm();
        writeeprom(3, 1);
      }
    }
  }

  if ((tempSensor[hiindex] >= 130.0) && (tempSensor[hiindex] - tempSensor[loindex] < 25)) {
    if (!AlarmFlagOTdisconnect) {
      flagCountOTdisconnect++;
      if (flagCountOTdisconnect > 16) {
        AlarmFlagOTdisconnect = true;
        alarm();
        writeeprom(3, 10);
      }
    }
  }

  if (AlarmFlagOT) {
    if (tempSensor[hiindex] < 95.0) {
      AlarmFlagOT = false;
      flagCountOT = 0;
    }
  }

  if ((tempSensor[hiindex] > 100.0) && (tempSensor[hiindex] - tempSensor[loindex] >= 25)) {  // if the sensors dont agree by a wide margin DONT disconnect the boat
    AlarmFlagOTdisconnect = false;
    if (!AlarmFlagSYS) {
      flagCountSYS++;
      if (flagCountSYS > 128) {
        AlarmFlagSYS = true;
        lockoutStartTime = millis();
        lockoutStartTimeSYS = millis();
        chargeLock = true;
        alarm();
        writeeprom(3, 11);
      }
    }
  }


  if (AlarmFlagOTdisconnect) {
    if (tempSensor[hiindex] <= 100.0) {
      AlarmFlagOTdisconnect = false;
      flagCountOTdisconnect = 0;
    }
  }


  if (tempSensor[loindex] < 36.0 && (abs(tempSensor[hiindex] - tempSensor[loindex]) >= 25)) {
    if (!AlarmFlagSYS) {
      flagCountSYS++;
      if (flagCountSYS > 16) {
        AlarmFlagSYS = true;
        lockoutStartTime = millis();
        lockoutStartTimeSYS = millis();
        alarm();
        writeeprom(3, 11);
      }
    }
  }

  if (tempSensor[loindex] < 36.0 && (abs(tempSensor[hiindex] - tempSensor[loindex]) < 25)) {
    if (currentMode == "BMS") {
      chargeLock = true;
      lockoutStartTime = millis();
    }
    if (!AlarmFlagUT) {
      flagCountUT++;
      if (flagCountUT > 16) {
        AlarmFlagUT = true;
        //writeeprom(3, 2);
      }
    }
  }

  if (AlarmFlagUT) {
    if (tempSensor[loindex] >= 39.0) {
      AlarmFlagUT = false;
      flagCountUT = 0;
    }
  }

  switch (req) {
    case 0:
      return loindex;
      break;

    case 1:
      return hiindex;
      break;

    case 2:
      return mintemp;
      break;

    case 3:
      return maxtemp;
      break;
  }
}
/*
  XX - 0
  OT - 1
  UT - 2
  OV - 3
  UV - 4
  DR - 5
  overflow 6
  disconnectLV - 7
  disconnectHV - 8
  OpenCell - 9
  disconnect OT -10
  system err - 11
  writeeprom(3, code);
*/



void logic() {  //add bank out of range,
  //<<<<<<<<<<<<<<<<<<<charging
  if (currentMode == "BMS" && !ChargeON && !balON) {  //if not charging AND not balancing
    if (!AlarmFlagOT && !AlarmFlagUT && !AlarmFlagOV && !AlarmFlagSYS) {  //Temp, Voltage & system integrity
      if (parameters[SCRchargeMode][0] == 0 ) {                                   //0 = Volt mode 
        if (cellV[minIndex] <= parameters[SCRstartChargeV][0] && cellV[maxIndex] <= parameters[SCRstopChargeV][0]) {  //if at LV trigger - charge
           flagCountStartCharge++;            //delay charge start in V mode
           if (flagCountStartCharge > 10) {
            startCharge();
           }
        }
      }
      if (parameters[SCRchargeMode][0] == 1) {  //1 = SOC mode
        if (SOC <= parameters[SCRSOCstart][0] && cellV[maxIndex] < parameters[SCRstopChargeV][0]) {
          startCharge();
        }
      }
    }
  }

  if (ChargeON) {                             //if charging
    if (parameters[SCRchargeMode][0] == 0) {  //volt mode
      if (cellV[maxIndex] > parameters[SCRstopChargeV][0]) {
        stopCharge();
      }
    }
    if (parameters[SCRchargeMode][0] == 1) {          //1 = SOC mode
      if (SOC >= parameters[SCRSOCstop][0]  || cellV[maxIndex] > parameters[SCRstopChargeV][0]) {  //when we reach V or SOC target
        stopCharge();
      }
    }

    if (AlarmFlagOT || AlarmFlagUT || AlarmFlagOV || AlarmFlagSYS) {  //if T or OV or system stop charging
      stopCharge();
    }
  }

  // emergency disconnects
  if (boatON) {
    if (AlarmFlagOVdisconnect && packVoltage > 15.6) {  //Voltage too far out of range - disconnect load
      stopCharge();
      stopBoat();
    }
    if (AlarmFlagUVdisconnect && (packVoltage < 13.6)) {
      //stopCharge();
      stopBoat();
    }
    if (AlarmFlagOTdisconnect) {  //hi temp disconnect
      stopCharge();
      stopBoat();
    }
  }
  if (!boatON){      //restart boat if measurements fall from disconnect to alarm levels but leave major alarm on
   if ( !AlarmFlagOVdisconnect && !AlarmFlagOTdisconnect && !AlarmFlagUVdisconnect) {
     startBoat();
   }
  }
  // sanity checks
  if (cellV[minIndex] < 2.1 || cellV[maxIndex] > 4.1 || amps0 > 100.0 || amps0 < -250.0) {
    if (!AlarmFlagSYS) {
      flagCountSYS++;
      if (flagCountSYS > 64) {
        AlarmFlagSYS = true;
        alarm();
        lockoutStartTime = millis();
        lockoutStartTimeSYS = millis();
        writeeprom(3, 11);
      }
    }
  }
}

void getAdcAmps() {
  long ADCu00val = 0;  //bias
  long ADCu01val = 0;  //shunt
  adcVol0 = 0;
  adcVol1 = 0;                  //shunt
  for (byte j = 0; j < 200; j++) {      //read 200x & average to suppress noise of inverter
    ADCu00val += adc0.analogRead(0);  //bias
    ADCu01val += adc0.analogRead(1);  //shunt
  }
  ADCu00val /= 200;  //get average
  ADCu01val /= 200;
  ADCu01val -= ADCu00val;  //remove bias
  if (ADCu01val == 1 || ADCu01val == -1) {
    ADCu01val = 0;
  }
  adcVol0 = (float(ADCu00val) * vref0);
  adcVol1 = (float(ADCu01val) * vref0);  // 2.048v ref gives .5mV / step
  amps0 = (adcVol1 / 50.0);              //200A/50mV shunt is .25 mV/ Amp, x50 OPA so 12.5mV/A @ ADC
  amps0 /= shuntR;                       // I=V/R
  amps0 *= shuntPolarity;                //invert for shunt polarity if required.   Reverse  AMPS
  amps0 -= .04;                         //subtract for own usage
}

void getAdc() {
  minIndex = 0;
  maxIndex = 0;
  float maxAllowedDrift = parameters[SCRmaxDrift][0] / 1000.0;
  float minVoltage = 4.096;
  float maxVoltage = 0;
  float cellArray[4] = { 0, 0, 0, 0 };

  for (byte i = 0; i < 4; i++) {  //read cell V  4 cells, 5 loops through
    cellArray[i] = 0;
    for (byte j = 0; j < 5; j++) {  //5 times
      cellArray[i] += adc1.analogRead(i);
    }
    if (cellArray[i] < 2000) {
      if (!AlarmFlagOC) {
        writeeprom(3, 9);
      }
    alarm();
    AlarmFlagOC = true;
    cellArray[i] = 5;
    }  
    cellArray[i] = (cellArray[i] / 5);  //get average
    cellV[i] = (cellArray[i] * vref1);  //convert to V
  }

  cellV[0] += (parameters[SCRC0Trim][0] / 1000.0);  //adjust cell Vs with trim values

  cellV[1] /= cellRdiv1;
  cellV[1] -= cellV[0];
  cellV[1] += (parameters[SCRC1Trim][0] / 1000.0);

  cellV[2] /= cellRdiv2;
  cellV[2] -= cellV[0] + cellV[1];
  cellV[2] += (parameters[SCRC2Trim][0] / 1000.0);

  packVoltage = (cellV[3] * 13.319) / 3.319;    // grab ADC output of top cell here Vout = Vs x R2 / (R1 + R2)   >> Vs = ( Vo(r1+R2) ) / R2
  cellV[3] /= cellRdiv3;
  cellV[3] -= cellV[0] + cellV[1] + cellV[2];
  cellV[3] += (parameters[SCRC3Trim][0] / 1000.0);

  Total_Voltage = 0;
  for (byte i = 0; i < 4; i++) {  //add cells for totalV, 
    Total_Voltage += cellV[i];
  }
  
 

  // get hi lo, drift

  for (byte i = 0; i < 4; i++) {
    if (cellV[i] > maxVoltage) {
      maxVoltage = cellV[i];
      maxIndex = i;
    }
    if (cellV[i] < minVoltage) {
      minVoltage = cellV[i];
      minIndex = i;
    }
  }

  if (maxVoltage >= parameters[SCRHVAlarm][0]) {
    if (!AlarmFlagOV) {
      flagCountOV++;
      if (flagCountOV > 8) {
        AlarmFlagOV = true;
        alarm();
        writeeprom(3, 3);
      }
    }
  }


  if (AlarmFlagOV) {
    if (maxVoltage <= parameters[SCRHVAlarm][0] - .015) {
      AlarmFlagOV = false;
      flagCountOV = 0;
      alarmOff();
    }
  }

  if (maxVoltage >= parameters[SCRHVdisconnect][0]) {
    if (!AlarmFlagOVdisconnect) {
      flagCountOVdisconnect++;
      if (flagCountOVdisconnect > 16) {
        AlarmFlagOVdisconnect = true;
        alarm();
        writeeprom(3, 8);
      }
    }
  }

  if (AlarmFlagOVdisconnect) {
    if (maxVoltage <= parameters[SCRHVAlarm][0]) {
      flagCountOVdisconnect = 0;
      AlarmFlagOVdisconnect = false;
      alarmOff();
    }
  }



  if (minVoltage <= parameters[SCRLVAlarm][0]) {
    if (!AlarmFlagUV) {
      flagCountUV++;
      if (flagCountUV > 8) {
        AlarmFlagUV = true;
        alarm();
        writeeprom(3, 4);
      }
    }
  }

  if (AlarmFlagUV) {
    if (minVoltage >= parameters[SCRLVAlarm][0] + .005) {
      AlarmFlagUV = false;
      flagCountUV = 0;
      alarmOff();
    }
  }

  if (minVoltage <= parameters[SCRLVdisconnect][0]) {
    if (!AlarmFlagUVdisconnect) {
      flagCountUVdisconnect++;
      if (flagCountUVdisconnect > 16) {
        AlarmFlagUVdisconnect = true;
        alarm();
        writeeprom(3, 7);
      }
    }
  }

  if (AlarmFlagUVdisconnect) {
    if (minVoltage >= parameters[SCRLVdisconnect][0] + .02) {    
    //if (minVoltage >= parameters[SCRLVAlarm][0]) {
      flagCountUVdisconnect = 0;
      AlarmFlagUVdisconnect = false;
      alarmOff();
    }
  }
  
    if (abs(Total_Voltage - packVoltage) > 1.0) {
      if (!AlarmFlagOC) {
        AlarmFlagOC = true;
        alarm();
        writeeprom(3, 9);
      }
    }
  
  if (abs(maxVoltage - minVoltage) > 1.0) {
    if (!AlarmFlagSYS) {
      AlarmFlagSYS = true;
      chargeLock = true;
      lockoutStartTime = millis();
      lockoutStartTimeSYS = millis();
      alarm();
      writeeprom(3, 11);
    }
  }


  voltageDrift = maxVoltage - minVoltage;
  if (voltageDrift > maxAllowedDrift) {  //set the alarm if cells drift out of balance
    if (!AlarmFlagDrift) {
      flagCountDrift++;
     /* if (flagCountDrift > 4) {
        lockoutStartTime = millis();
        chargeLock = true;
      }
    */
      if (flagCountDrift > 16) {
        AlarmFlagDrift = true;  //NOK but let it be.  Set the alarm present indicator.  No major notifications.  Alow charging
        writeeprom(3, 5);
      }
    }
  }
  if (voltageDrift <= maxAllowedDrift - .01) {  //10mv hysterisis for canceling alarm
    AlarmFlagDrift = false;
    flagCountDrift = 0;
  }
}



void alarm() {
  digitalWrite(ALARMpin, HIGH);
  AlarmFlag = true;
}

void alarmOff() {
  digitalWrite(ALARMpin, LOW);
  AlarmFlag = false;
}



void startCharge() {
  if (!chargeLock) {
    if (!ChargeON && (currentMode == "BMS" || currentMode == "DUM")) {  //if not charging start charging
      lcd.clear();
      lcd.print("START CHARGE");
      flagCountStartCharge = 0;
      digitalWrite(Solar_ON, HIGH);
      delay(RelayOnTime);
      digitalWrite(Solar_ON, LOW);
      delay(RelayOnTime);
      digitalWrite(Alt_ON, HIGH);
      delay(RelayOnTime);
      digitalWrite(Alt_ON, LOW);
      delay(RelayOnTime);
      digitalWrite(AcChrge_ON, HIGH);
      delay(RelayOnTime);
      digitalWrite(AcChrge_ON, LOW);
      delay(RelayOnTime);
      ChargeON = true;


      delay(1000);
    }
  }
}


void captureEndOfCharge(){            //add total AH added?  
  getAdc();
  endOfChargeData[0] = cellV[minIndex];
  endOfChargeData[1] = cellV[maxIndex];
  endOfChargeData[2] = amps0;
  endOfChargeData[3] = Total_Voltage;
  endOfChargeData[4] = packVoltage;
  endOfChargeData[5] = voltageDrift;
  endOfChargeMinCell = minIndex;
  endOfChargeMaxCell = maxIndex;
}


void stopCharge() {
  if (ChargeON) {  //if charging - stop charge
    lcd.clear();
    lcd.print("STOP CHARGE");
    captureEndOfCharge();
    digitalWrite(Solar_OFF, HIGH);
    delay(RelayOnTime);
    digitalWrite(Solar_OFF, LOW);
    delay(RelayOnTime);
    digitalWrite(Alt_OFF, HIGH);
    delay(RelayOnTime);
    digitalWrite(Alt_OFF, LOW);
    delay(RelayOnTime);
    digitalWrite(AcChrge_OFF, HIGH);
    delay(RelayOnTime);
    digitalWrite(AcChrge_OFF, LOW);
    delay(RelayOnTime);
    ChargeON = false;
    delay(1000);
    lockoutStartTime = millis();
    chargeLock = true;
    cycleCount += 1;
  }
}

void startBoat() {
  if (!boatON) {
    lcd.clear();
    lcd.print("START BOAT");
    digitalWrite(Load_ON, HIGH);
    delay(RelayOnTime);
    digitalWrite(Load_ON, LOW);  
    boatON = true;
    delay(1000);
  }
}


void stopBoat() {
  if (boatON) {
    lcd.clear();
    lcd.print("STOP BOAT");
    digitalWrite(Load_OFF, HIGH);
    delay(RelayOnTime);
    digitalWrite(Load_OFF, LOW);
    boatON = false;
    delay(1000);
  }
}





void getamphours() {  //  show amps charged at charge end?
  if (lastAmpTime > millis()) {
    lastAmpTime = millis();  //rollover.  skip this cycle
  }
  unsigned long elapsedTime = millis() - lastAmpTime;  // millis max value= 4,294,967,295.
  lastAmpTime = millis();
  float increment = (amps0 * elapsedTime);
  increment /= 1000;  // get seconds
  if (amps0 > 0) {    //apply efficiency
    increment *= (parameters[SCRefficiency][0] / 100.0);
  }
  ampSeconds += increment;  //accumulate
  /*
    full synch
     if v > 3.6 its fully charged??.
     if v > ? and tail current < .05 it's fully charged.
    3.475, 1%, 1 minute ??
  */

  ampHours = ampSeconds / 3600.0;
  bankAH = parameters[SCRbankCapacity][0] + ampHours;

  if (bankAH > parameters[SCRbankCapacity][0]) {  //never show greater than selected AH rating
    bankAH = parameters[SCRbankCapacity][0];
  }
  SOC = (bankAH / parameters[SCRbankCapacity][0]) * 100.0;
  if (SOC >= 100) {  //never show greater than 100% SOC
    SOC = 100;
    if (ampHours > 0) {  //never show greater positive AH
      ampHours = 0;
      ampSeconds = 0;
    }
  }
  if (SOC < 0) {  //never show less than 0% SOC
    SOC = 0;
  }
}


/*
  XX - 0
  OT - 1
  UT - 2
  OV - 3
  UV - 4
  DR - 5
  overflow 6
  disconnectLV - 7
  disconnectHV - 8
  OpenCell - 9
  disconnect OT -10
  system err - 11
  writeeprom(3, code);
*/


bool writeeprom(byte etask, int code) {  //use writeeprom(task, code)
  //  noInterrupts();
  bool epromWritten = 0;
  int eeAddress = 0;
  float f = 0;
  float T = 0;
  unsigned long E = 0;
  unsigned long CRC = 0;
  unsigned int elength = EEPROM.length();
  EEPROM.get(0, f);
  switch (etask) {
    case 1:  //write full eprom
      busy(anchorFace);
      EEPROM.put(eeAddress, 99.44);
      eeAddress += sizeof(float);
      for (int i = 0; i <= numOfScreens; i++) {
        EEPROM.put(eeAddress, (parameters[i][0]));
        eeAddress += sizeof(float);
      }
      E = eeprom_crc();
      EEPROM.put((elength - sizeof(long)), E);  //store CRC at end of eeprom
      delay(500);
      lcd.clear();
      break;

    case 2:  //read eprom , restore if available

      EEPROM.get((elength - sizeof(long)), E);  //retrieve stored CRC
      CRC = eeprom_crc();
      if (E == CRC) {
        if (f == 99.44) {
          epromWritten = 1;
          eeAddress = sizeof(float);
          for (int i = 0; i <= numOfScreens; i++) {
            EEPROM.get(eeAddress, (parameters[i][0]));
            eeAddress += sizeof(float);
          }
        }
      } else {
        epromWritten = 0;
        EEPROM.put(0, 0);
      }
      break;


    case 3:  //error history write

      alarmCount++;
      if (alarmCount >= 25) {
        alarmCount = 1;
        eeAddress = alarmHistoryPointer + sizeof(int);
        EEPROM.put(eeAddress, 6);  //record overflow
        alarmCount = 2;            //then record current alarm
      }
      //     delay(2000);
      eeAddress = alarmHistoryPointer;
      EEPROM.put(eeAddress, alarmCount);
      //     delay(200);
      eeAddress = alarmHistoryPointer + (alarmCount * sizeof(int));
      EEPROM.put(eeAddress, code);
      ///now write data at time of alarm -6 floats stored
      eeAddress = alarmDataPointer;
      EEPROM.put(eeAddress, Total_Voltage);
      eeAddress += sizeof(float);
      EEPROM.put(eeAddress, packVoltage);
      eeAddress += sizeof(float);
      EEPROM.put(eeAddress, cellV[minIndex]);
      eeAddress += sizeof(float);
      EEPROM.put(eeAddress, cellV[maxIndex]);
      eeAddress += sizeof(float);
      T = getTemps(2);
      EEPROM.put(eeAddress, T);
      eeAddress += sizeof(float);
      T = getTemps(3);
      EEPROM.put(eeAddress, T);
      eeAddress += sizeof(float);

      //now write flag status
      EEPROM.put(eeAddress, boatON);
      eeAddress += sizeof(bool);
      EEPROM.put(eeAddress, ChargeON);
      eeAddress += sizeof(bool);
      EEPROM.put(eeAddress, AlarmFlagOV);
      eeAddress += sizeof(bool);
      EEPROM.put(eeAddress, AlarmFlagUV);
      eeAddress += sizeof(bool);
      EEPROM.put(eeAddress, AlarmFlagOT);
      eeAddress += sizeof(bool);
      EEPROM.put(eeAddress, AlarmFlagUT);
      eeAddress += sizeof(bool);
      EEPROM.put(eeAddress, AlarmFlagOTdisconnect);
      eeAddress += sizeof(bool);
      EEPROM.put(eeAddress, AlarmFlagDrift);
      eeAddress += sizeof(bool);
      EEPROM.put(eeAddress, AlarmFlag);
      eeAddress += sizeof(bool);
      EEPROM.put(eeAddress, AlarmFlagOC);
      eeAddress += sizeof(bool);
      EEPROM.put(eeAddress, AlarmFlagSYS);
      eeAddress += sizeof(bool);
      EEPROM.put(eeAddress, balON);  //balance
      eeAddress += sizeof(bool);

      EEPROM.put(eeAddress, AlarmFlagOTdisconnect);  //OT diconnect
      eeAddress += sizeof(bool);
      EEPROM.put(eeAddress, AlarmFlagOVdisconnect);  //OV diconnect
      eeAddress += sizeof(bool);
      EEPROM.put(eeAddress, AlarmFlagUVdisconnect);  //UV disconnect
      eeAddress += sizeof(bool);
      // delay(20);
      break;

    case 4:  //was EEPROM written?

      if (f == 99.44) {
        epromWritten = 1;
      }
      break;
  }
  //  interrupts();
  return epromWritten;
}
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

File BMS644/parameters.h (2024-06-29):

/*
  math for Res Div network
  Vout = Vin * R2 / R1 + R2
  R2/R1+R2 = ratio
  Vin(batteyV) =  Vout / ratio
  C0 = direct read
  C1 = 10 / 20 = .5
  C2 = 5 / 15 = .333333
  C3 = 3.32 / 13.32 = .249249
  Total_Voltage = 4 / 14 = .2857


  TODO
add/modify:
tail current of .05 to .033 ?

Waiting for pack??

pulse audible alarm  use LCD flash routine,   minor alarm, major alarm??
clean up low temp & set to dum mode
verify time in status before actions like start, stop & diconnect.  verify reset timers , counters
accumulate overcharge AHs?  learn effiency?
history??  what kind?  
VERIFY LOGIC     rework HV & LV cut & sanity checks, 
    
Broken:
if 1 cell open display wrong because of ABS calc.  do test
sometimes reboots on eprom save 


v1.2.0 change log:
implement balance with adjustable start V, predefined time 20min 50mV drift to start.  (~1AH = 40 min) , reporting on cell V page, add bal to display cycle
fixup drift, set alarm no lockout
seperate amp sense & cell V sense.  high freq amp sense (~160ms), cell V sense 2 sec interval
lower ADC SPI freq to 1mHz  & take and average 200 samples for amps
Hardware - remove C14, C16 from mainboard.  Remove bias capacitor from shunt.  Verify INA213 50V/V
remove "reset EEPROM" ,remove all load functions , remove several display cycles , add # of T sense option
allow charging after boat off on LV disconnect, remove tail current mode, remove shunt val, menu changes,
auto write eeprom, add .04 Amps for BMS consumption,allows connecting grnd direct to battery negative instead of shunt 
Remove temperature settings from menu.  hardcoded at start=37F stop=100F disconnect=130F
add cell V to cell trim screens, add stats for last charge data to show cells,


v 1.2.1(b)
changed some pin assignments to match new hardware & balance board.  use top cell for pack voltage calc.  
set balance time to 10 min (100mA).  dont record UT event to EEPROM.  Display packvoltage instead of sum of cells
fixup Lv disconnect logic.  set lv alarm 10mV higher than Lv disco if it was lower, reworked menu input - now requires button 
press to set value.  Improved open cell routine.  cell # 0 vol can remain high - no bleed resistor to gnd.  Cell #3 triggers both hv & lv disco

NEED reset lvdisco bounds , cycle count prbly wrong , fixup OC logic

*/


//LCD Menu Logic
const int numOfScreens = 27;
int currentScreen = 0;

const String screens[numOfScreens][4] = {  //Item, Unit, display type, BMS, DUM or ALL display
  {"Bank Capacity", " AH's", "I", "ALL"}, 
  {"Start Charge", " Volts", "F", "BMS"}, 
  {"Stop Charge", " Volts", "F", "BMS"}, 
  {"SOC Start", " %SOC", "I", "BMS"}, 
  {"SOC Stop", " %SOC", "I", "BMS"},   
  {"Charge Mode", " 0=V 1=SOC", "I", "BMS"},  
  {"Chg To Full Now", " 1=Yes", "I", "BMS"}, 
  {"Efficiency", " %", "F", "BMS"}, 
  {"HV Alarm", " Volts", "F", "BMS"}, 
  {"LV Alarm", " Volts", "F", "BMS"}, 
  {"HV Disconnect", " Volts", "F", "BMS"}, 
  {"LV Disconnect", " Volts", "F", "BMS"}, 
  {"MaxDrift", " mV", "I", "BMS"}, 
  {"C1 Trim", " mV", "I", "BMS"}, 
  {"C2 Trim", " mV", "I", "BMS"}, 
  {"C3 Trim", " mV", "I", "BMS"}, 
  {"C4 Trim", " mV", "I", "BMS"}, 
  {"Balance Allow V", " Volts", "F", "BMS"}, 
  {"Show Cells & Vs", " 1=Show", "I", "ALL"}, 
  {"Show Temps", " 1=Show", "I", "ALL"},
  {"Show Alarms", " 1=Show", "I", "ALL"},
  {"Clear Alrm", " 1=Clear", "I", "ALL"},   
  {"Mode 0=BMS 1=OFF", "    2=DUM", "I", "ALL"},  
  {"Encoder Direction", " 0 or 1 ", "I", "ALL"},  
  {"SOC", "AH", "I", "ALL"},
  {"Shunt Polarity" , "-1 or 1", "F" , "ALL"},
  {"# of T Sense" , "   0,1,2,3", "I" , "ALL"},
};


float parameters[numOfScreens] [2] = {
  280, 280, //bank capacity
  3.30, 3.30, //start charge
  3.6, 3.6, //stop charge     
  75, 75, //SOC start
  90, 90, //SOC stop
  0, 0, //Charge Mode   0=V, 1=SOC
  0, 0, //chg to full now
  98, 98, //efficiency
  3.7, 3.7, //hvalarm
  3.1, 3.1, //lvalarm
  3.8, 3.8, //Hv disconnect   
  2.5, 2.5, //Lv disconnect
  100, 100, //drift
  0, 0,  //c0 trim
  0, 0, //c1 trim
  0, 0, //c2 trim
  0, 0, //c3 trim
  3.6, 3.6, //balance v
  0, 0, //show cells
  0, 0, //show temps
  0, 0, //show error
  0, 0, //reset alarm
  1, 1, //op mode BMS, DUM, OFF    <<<<<<<<<initially off to alow cell connect without alarm
  1, 1, //encoder direction
  0, 0, //current SOC
  1.0, 1.0, //shunt polarity
  2, 2  //# of temp sensors
};
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

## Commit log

2024-06-08 Rework menu input, open cell detection
    [BMS644Base.stl, BMS644Lid-w-pins.stl, BMS_Main_Stencil.stl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]
2024-06-08 Add images of boards
2024-06-08 update PCBs
    [BOM_BalanceBoard-vB_2024-06-08.csv, BOM_Main-vB_2024-06-08.csv, BOM_Relay-Board-vB_2024-06-08.csv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]
2024-06-08 add overview schematic
2024-06-10 update hardware
    [BOM_Main-vB - BOM_Main-vB.tsv, BOM_ShuntBoard - BOM_ShuntBoard.tsv]
2024-06-11 Update extrasBOM.md
    bom
2024-06-18 adj temperature settings
2024-06-19 voltage menu cleanup
2024-06-19 balance board
2024-06-20 Update Schematic_Typical-Layouts.pdf
    update overview
2024-06-29 delay start charge
